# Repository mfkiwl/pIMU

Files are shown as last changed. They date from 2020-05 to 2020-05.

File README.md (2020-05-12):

# pIMU: Unidad de medición inercial portatil

pIMU es una unidad de medición inercial (acelerómetro, giroscopio y magnetómetro) capaz de enviar los datos muestreados de forma inalámbrica. 

## Características

· Dimensiones: 18x12mm

· Tensión de trabajo: 3,5V-1V

· Consumo: 9mA (consumo optimizado en el código)

· Transmisor y protcolo: NRF24L01

· Frecuencia de emisión: 2,4GHz

## Descripción

El sensor principal encargado de la recolección de datos es un MPU9250. Éste es controlado por un microcontrolador Atmega328p que, a su vez, envía los datos en bruto a un módulo NRF24L01 para su transmisión. El regulador de tensión será un TLV61225, capaz de elevar tensiones de hasta 0,7V a los 3,3V necesarios para el funcionamiento del resto de integrados.

Este módulo está pensado para su alimentación mediante un supercondensador de tensión nominal entre 2,5V y 3,5V. Dado su bajo consumo, el uso de un supercondensador permite tiempos de uso superiores a las 2h con tiempos de carga de apenas unos segundos. 

El Atmega328p será flasheado con un el firmware Optiboot, con el fin de poder utilizar lenguaje Arduino en su programación y permitir que cualquier persona sin conocimientos de este micro concreto pueda programarlo a su gusto. La PCB cuenta con pads de soldadura suficientemente grandes asociados a los pines TX, RX y RST del microcontrolador, para poder subir sketches de forma sencilla mediante un adaptador USB-UART.  

## Instrucciones de montaje

Una vez adquiridos todos los componentes (Bill Of Materials disponible en el proyecto de Kicad), los pasos a seguir para conseguir una pIMU funcionando serán:

1. Soldadura del TLV, Atmega, sus condensadores de desacoplo y la resistencia de pull-up para el reset

2. Conexión de la interfaz SPI al ordenador. Para ello, podemos tomar como puertos de SPI los pines correspondientes al módulo NRF24L01 aún sin soldar y conectarlos a un programador ISP. En caso de no disponer de dicho programador, es posible fabricarse uno con un Arduino https://www.arduino.cc/en/Guide/ArduinoISP.

3. Cambio de los fuses (¿fusibles?) del micro. Para ello se usará el programa avrdude. Buscamos optimizar el espacio reservado al bootloader, utilizar el reloj interno a 8MHz para un menos consumo y desactivar o rebajar la detección de Brown-Out. En nuestro caso, los valores elegidos son LowFuse: 0xFF; HighFuse: 0xDE; ExtendedFuse: 0xFD. 

4. Grabado del bootloader. Existen múltiples formas de realizar este paso. La opción recomendada es hacer uso del programa de Nick Gammon https://www.gammon.com.au/bootloader. Este programa permite además cambiar los fuses de forma directa, en caso de tener problemas con avrdude en el paso anterior. La opción Lilypad 8MHz incluye ya algunas de las opciones mencionadas, como el uso de reloj interno u optimización del espacio de arranque.

5. Comprobación del bootloader. Para ello, basta soldar tres cables a los pines TX, RX y RST del pIMU, conectarlos a un conversor de USB-UART y probar a subir un sketch de Arduino (seleccionando la placa Lilypad 8MHz en caso de haber optado por esa opción en el caso anteior)

6. Soldadura del resto de componentes.

7. Programación del Atmega con el código final. Este código está disponible en este repo, e incluye la adquisicion de datos y su envío de forma periódica mediante uso de la interrupción WDT y la configuración a modo dormido del micro entre mediciones.

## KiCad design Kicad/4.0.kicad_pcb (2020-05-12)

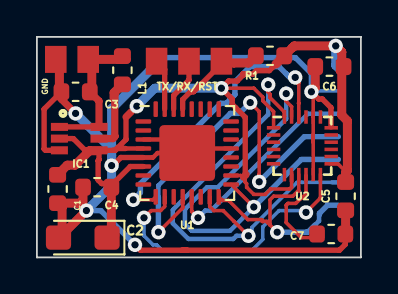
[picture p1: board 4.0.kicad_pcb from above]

Board: 2 copper layers, 18.0 x 12.2 mm, 15 parts (1 on the bottom side), 15 nets.

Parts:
C1, C5, C7: 0.1uF; C_0603_1608Metric
C2: 4.7uF; CP_EIA-3216-18_Kemet-A
C3, C4: 10uF; C_0603_1608Metric
C6: 10nF; C_0603_1608Metric
GND: Conn_01x02_Female; ConBAT
IC1: TLV61225
L1: 4.7uH; L_0603_1608Metric
NRF24L01: Módulo NRF24L01; ConNRF_3
R1: 10K; R_0603_1608Metric
TX/RX/RST: Conn_01x03_Female; ConPRG
U1: ATmega328P-MU; QFN-32-1EP_5x5mm_P0.5mm_EP3.1x3.1mm
U2: MPU-9250; QFN-24_3x3mm_P0.4mm

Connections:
+3V3: C1.1, C2.1, C4.1, C5.1, C6.1, IC1.2, IC1.4, NRF24L01.1, R1.1, U1.4, U1.6, U1.18, U2.1, U2.8, U2.13
/CE_I: U1.9, U2.22
/CE_R: NRF24L01.3, U1.13
/CSN: NRF24L01.4, U1.12
/MISO: NRF24L01.7, U1.16, U2.9
/MOSI: NRF24L01.6, U1.15, U2.24
/SCK: NRF24L01.5, U1.17, U2.23
Earth: C1.2, C2.2, C3.2, C4.2, C5.2, C6.2, C7.2, GND.2, IC1.3, NRF24L01.2, U1.3, U1.5, U1.21, U1.33, U2.11, U2.18, U2.20
INT: U1.10, U2.12
unnamed: C7.1, U2.10
unnamed: IC1.5, L1.2
RES: R1.2, TX/RX/RST.3, U1.29
RX: TX/RX/RST.2, U1.30
TX: TX/RX/RST.1, U1.31
VCC: C3.1, GND.1, IC1.1, IC1.6, L1.1

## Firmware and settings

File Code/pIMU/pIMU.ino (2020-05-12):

/*
 * portable Inertial Measurement Unit
 * 
 * Instructions and more can be found at:
 * 
 * https://github.com/pepassaco/pIMU
 * 
 * by Pablo Alvarez Dominguez.
 */
 
#include <SPI.h>
#include <nRF24L01.h>
#include <RF24.h>
#include "MPU9250.h"
#include <avr/sleep.h>
#include <avr/power.h>
#include <avr/wdt.h>


MPU9250 IMU(SPI,5);     //IMU MPU9250 por SPI, con CS en pin 5
int status;             //Estado de la IMU
double msg[3];          //Array donde se almacenan los valores del acelerometro

RF24 radio(9, 8);       // CE, CSN el emisor de radio NRF24L01     
const byte address[6] = "00001"; 

volatile int f_wdt=1;   //Flag para el WDT


ISR(WDT_vect)           //Rutina de atencion a la interrupcion del watchdog 
{
  if(f_wdt == 0)        //se limpia el flag
  {
    f_wdt=1;
  }
}





void imuConf(){                 //Configuracion inicial de la imu
  status = IMU.begin();
  if (status < 0) {             //Si no se inicia, no hagas nada

    while(1) {
    }
    
  }
}

void nrfConf(){                                 //Configuracion de la radio
  radio.begin();                                //Inicio
  radio.openWritingPipe(address);               //Se abre una tuberia de datos en la direccion especificada
  radio.setPALevel(RF24_PA_MIN);                //Nivel de potencia de tx al minimo 
  radio.stopListening();                        //Desactiva la escucha (solo tx)
}

void wdtConf(){                                 //Configuracion del WDT (registros del microcontrolador)
  
  /* Clear the reset flag. */
  MCUSR &= ~(1<<WDRF);
  
  /* In order to change WDE or the prescaler, we need to
   * set WDCE (This will allow updates for 4 clock cycles).
   */
  WDTCSR |= (1<<WDCE) | (1<<WDE);

  /* set new watchdog timeout prescaler value */
  WDTCSR = 0<<WDP0 | 0<<WDP1 | 0<<WDP2 | 0<<WDP3; /* 16 miliseconds */
  
  /* Enable the WD interrupt (note no reset). */
  WDTCSR |= _BV(WDIE);
}




void enterSleep(void){                    //Metodo que duerme al micro
  
  set_sleep_mode(SLEEP_MODE_PWR_DOWN);    //Selecciona como modo el apagado del micro
  
  sleep_mode();                           //Entra en el modo seleccionado
  
  ADCSRA = 0;                             //Desactiva el ADC
  power_all_disable();                    //Desactiva todos los modulos

  power_timer0_enable();                  //Reactiva el timer0
  power_spi_enable();                     //Reactiva el SPI
}




void manda() {
  
  IMU.readSensor();
  
  msg[0] = IMU.getAccelX_mss();
  msg[1] = IMU.getAccelY_mss();
  msg[2] = IMU.getAccelZ_mss();

  radio.powerUp();
  radio.write(&msg, sizeof(msg));
  radio.powerDown();  
  
}






void setup() {
  
  ADCSRA = 0;
  
  power_all_disable(); 

  power_timer0_enable();
  power_spi_enable();
  
  imuConf();
  nrfConf();
  wdtConf();  
  
}


void loop(){
  
  if(f_wdt == 1){
    manda();
    f_wdt = 0;      //limpiamos el flag
    enterSleep();
  }
  
}
